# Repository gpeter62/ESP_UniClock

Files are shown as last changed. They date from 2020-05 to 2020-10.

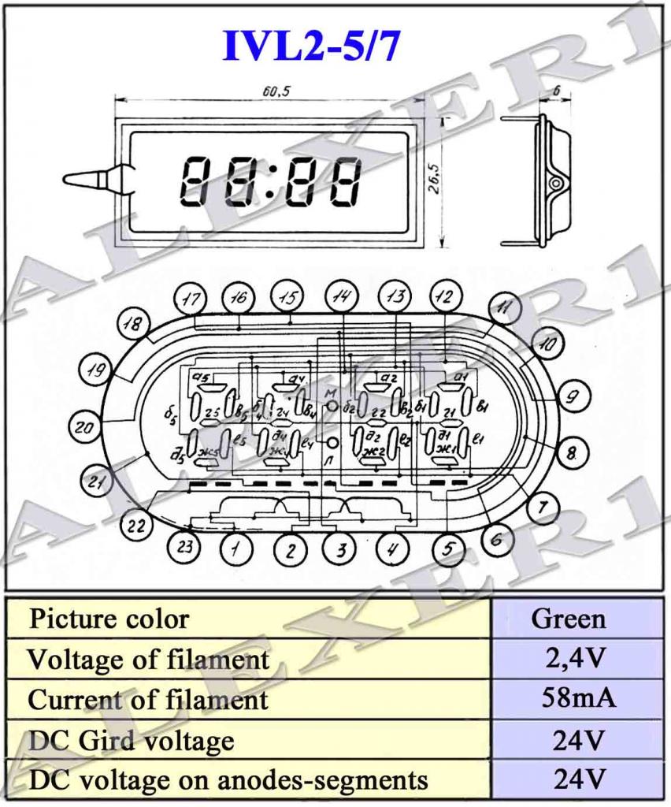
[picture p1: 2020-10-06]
Datasheets/IVL2-7_5-VFD-Specs.jpg

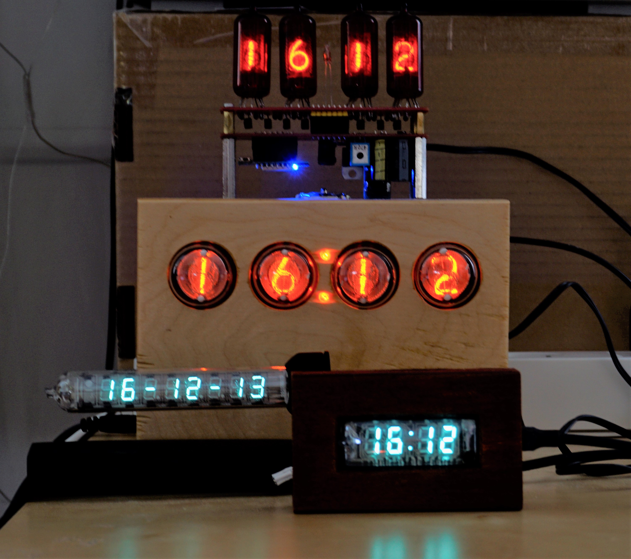
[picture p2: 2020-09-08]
_DSC3223.jpg

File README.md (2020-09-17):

# ESP_UniClock v1.4

Universal WifiClock with Nixie, VFD, Numitron tubes or LED display
Number of digits: 4, 6 or 8

Adjustable day and night brightness

ANIMATE: 5 animation modes, 6 means random animation

Hardver:

Wemos D1 Mini (or any other ESP8266 modul) 160MHz

Drivers: SN74141 (multiplex or latch), MAX6921, MAX7219, MM5450

Optional: DS18B20 temperature sensor  (1 or 2 sensor)
 
Optional: DHT11/DHT22 temperature/humidity sensor

Optional: DS3231 RTC Clock with Wifi/Manual mode switch and pushbuttons to set the date/time - standalone mode possible without WiFi

Optional: GPS modul (to use instead of Wifi sync  - standalone mode, only web setup screen available)

User defined pin numbers for digits and segments

Web page for setup. See: Screenshot.png

-- External libraries used ------------------------------------------------------------------------------

Time, Timezone, NtpClient, Wifimanager       Optional: DS3231, TinyGPSPlus, 
--------------------------------------------------------------------------------------------------------

More info:

Peter Gautier
 Email: gautier.p62@gmail.com

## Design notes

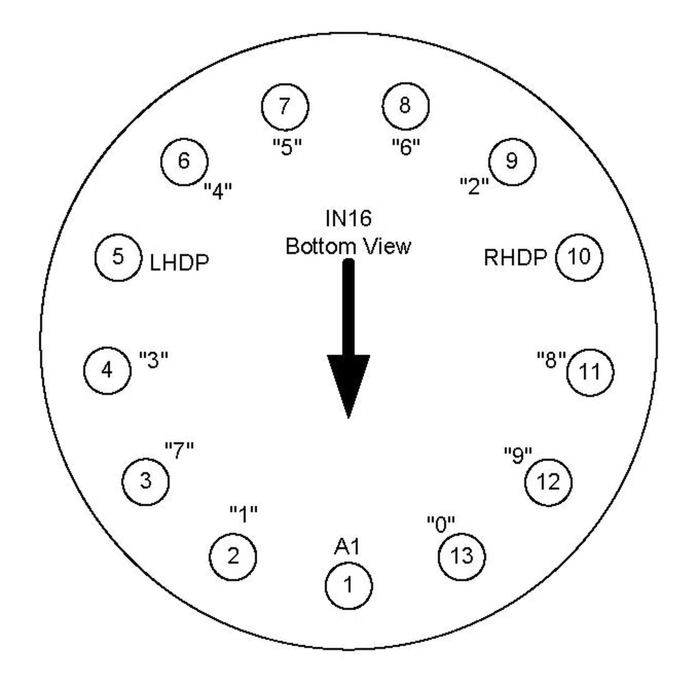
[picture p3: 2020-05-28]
Datasheets/in16_pinout__26559.1553434410.webp

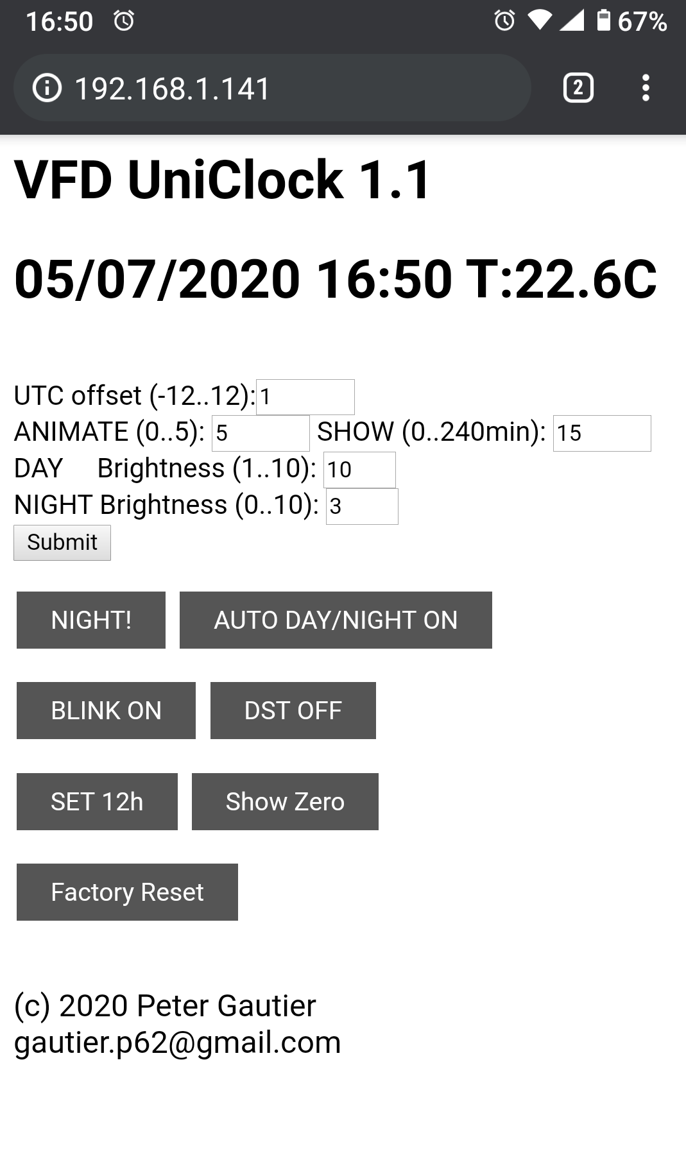
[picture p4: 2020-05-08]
Screenshot.png

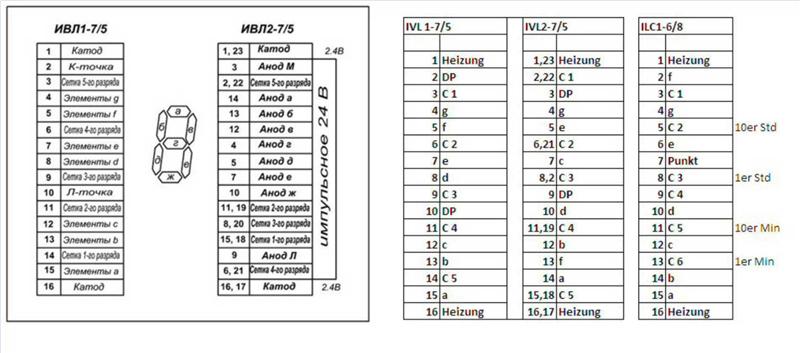
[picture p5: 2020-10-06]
Datasheets/IVL2-57 Pins.jpg

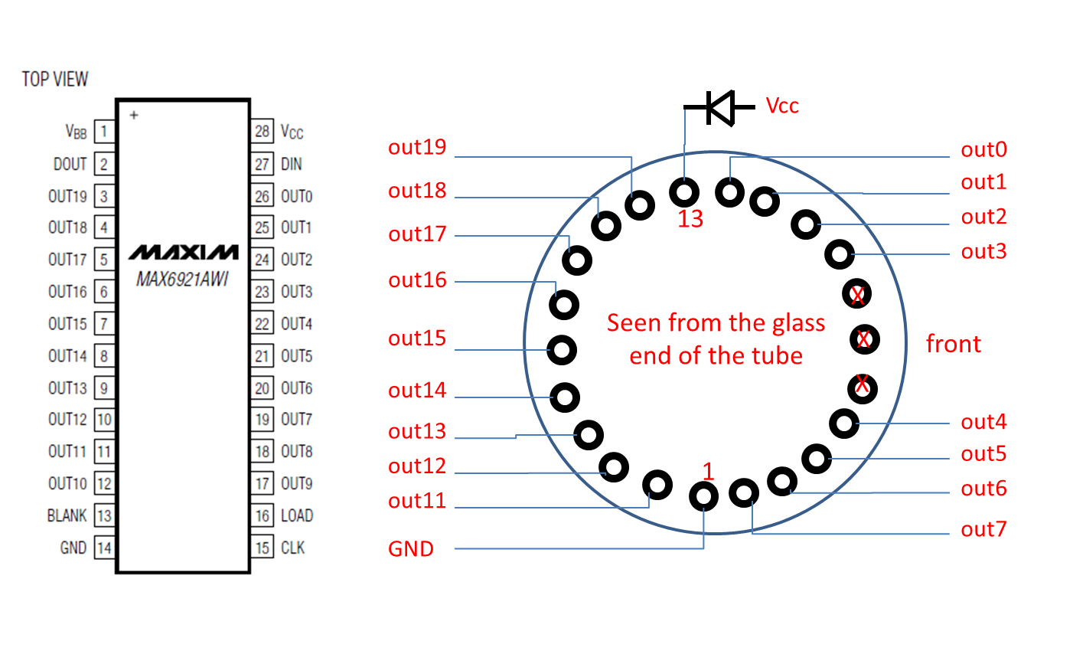
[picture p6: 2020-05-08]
Datasheets/max6921_-_IV18.png

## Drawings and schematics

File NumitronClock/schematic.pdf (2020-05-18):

6 FTDI | R⁵ | R⁶ R⁷

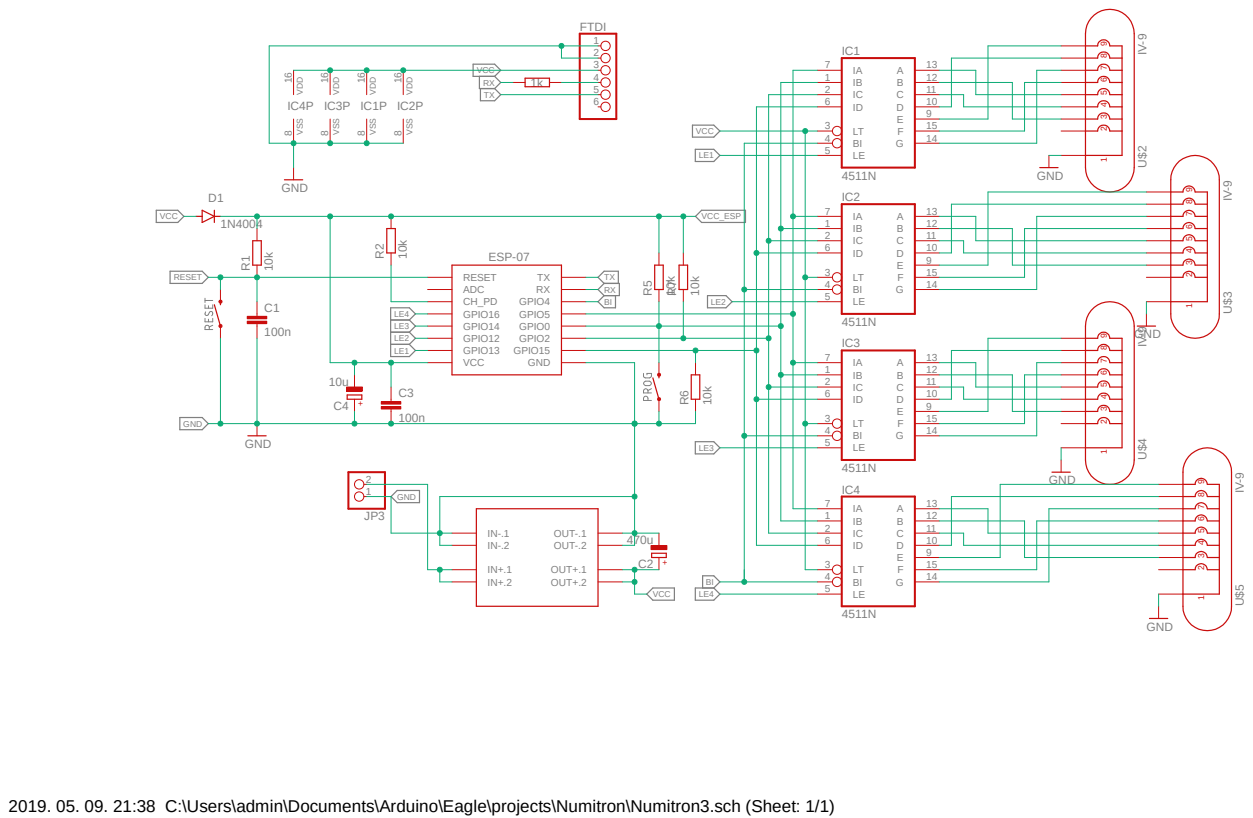
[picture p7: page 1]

ID 6 | 10 C
LT 3 BI 4 LE 5 | 9

IB 1 | 12 A
IC 2 | 11 B

IB 1 | 12 A 11 B
IC 2

2019. 05. 09. 21:38 C:\Users\admin\Documents\Arduino\Eagle\projects\Numitron\Numitron3.sch (Sheet: 1/1)

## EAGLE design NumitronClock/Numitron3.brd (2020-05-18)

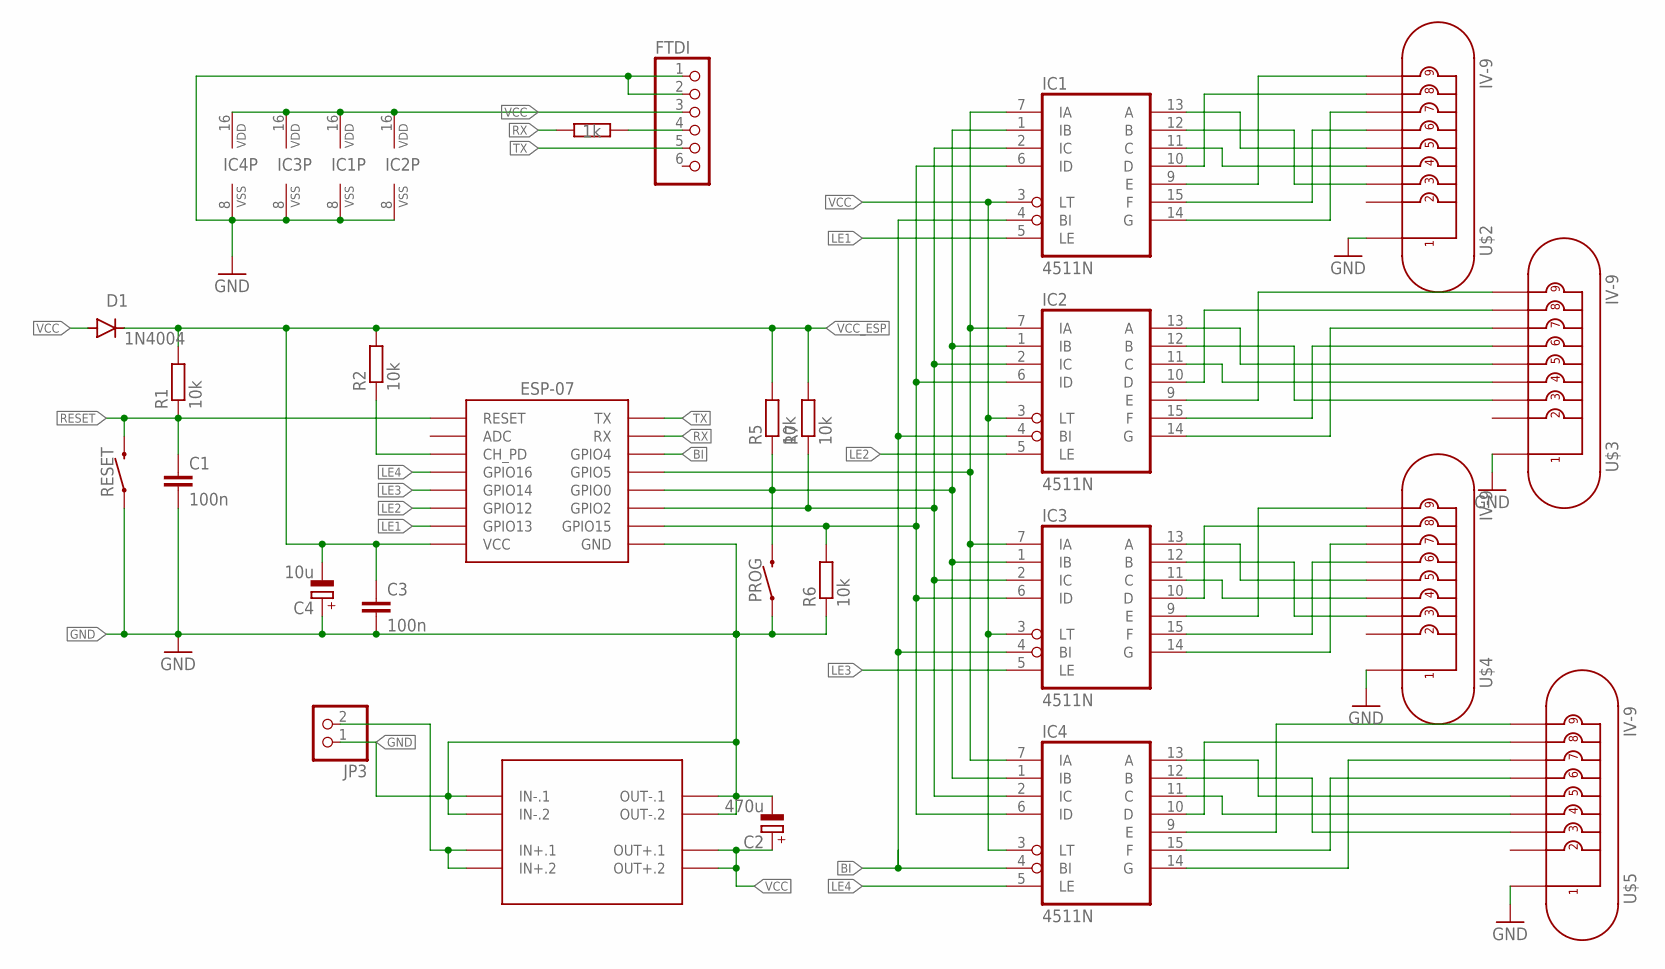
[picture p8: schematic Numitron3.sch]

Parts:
C1: 100n; C025-024X044
C2: 470u; B45181B
C3: 100n; C025-050X050
C4: 10u; B45181A
D1: 1N4004; DO41-10
ESP-07: ESP12SMD; ESP12-SMD
FTDI: PINHD-1X6; 1X06
IC1, IC2, IC3, IC4: 4511N; DIL16
JP3: PINHD-1X2; 1X02
PROG: MOMENTARY-SWITCH-SPST-PTH-6.0MM; TACTILE_SWITCH_PTH_6.0MM
R1, R2, R5, R6, R7: 10k; 0204/7
R4: 1k; 0204/7
RESET: MOMENTARY-SWITCH-SPST-PTH-6.0MM; TACTILE_SWITCH_PTH_6.0MM
U$2, U$3, U$4, U$5: IV-9
U$6: DC-DC-STEP-DOWN-MP1584

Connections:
BI: ESP-07.GPIO4, IC1.4 (BI), IC2.4 (BI), IC3.4 (BI), IC4.4 (BI)
GND: C1.2, C2.-, C3.2, C4.+, ESP-07.GND, FTDI.1, FTDI.2, IC1.8 (VSS), IC2.8 (VSS), IC3.8 (VSS), IC4.8 (VSS), JP3.1, PROG.1, R6.1, RESET.1, U$2.1, U$3.1, U$4.1, U$5.1, U$6.IN-.1, U$6.IN-.2, U$6.OUT-.1, U$6.OUT-.2
LE1: ESP-07.GPIO13, IC1.5 (LE)
LE2: ESP-07.GPIO12, IC2.5 (LE)
LE3: ESP-07.GPIO14, IC3.5 (LE)
LE4: ESP-07.GPIO16, IC4.5 (LE)
unnamed: ESP-07.GPIO5, IC1.7 (IA), IC2.7 (IA), IC3.7 (IA), IC4.7 (IA)
unnamed: ESP-07.GPIO0, IC1.1 (IB), IC2.1 (IB), IC3.1 (IB), IC4.1 (IB), PROG.3 (2), R5.1
unnamed: ESP-07.GPIO2, IC1.2 (IC), IC2.2 (IC), IC3.2 (IC), IC4.2 (IC), R7.1
unnamed: ESP-07.GPIO15, IC1.6 (ID), IC2.6 (ID), IC3.6 (ID), IC4.6 (ID), R6.2
unnamed: IC1.13 (A), U$2.5
unnamed: IC1.12 (B), U$2.3
unnamed: IC1.11 (C), U$2.4
unnamed: IC1.10 (D), U$2.8
unnamed: IC1.9 (E), U$2.9
unnamed: IC1.15 (F), U$2.6
unnamed: IC1.14 (G), U$2.7
unnamed: IC2.14 (G), U$3.7
unnamed: IC2.12 (B), U$3.3
unnamed: IC2.13 (A), U$3.5
unnamed: IC2.10 (D), U$3.8
unnamed: IC2.9 (E), U$3.9
unnamed: IC2.11 (C), U$3.4
unnamed: IC2.15 (F), U$3.6
unnamed: IC3.9 (E), U$4.9
unnamed: IC3.13 (A), U$4.5
unnamed: IC3.12 (B), U$4.3
unnamed: IC3.15 (F), U$4.6
unnamed: IC3.14 (G), U$4.7
unnamed: IC3.10 (D), U$4.8
unnamed: IC3.11 (C), U$4.4
unnamed: IC4.14 (G), U$5.7
unnamed: IC4.15 (F), U$5.6
unnamed: IC4.9 (E), U$5.9
unnamed: IC4.10 (D), U$5.8
unnamed: IC4.11 (C), U$5.4
unnamed: IC4.12 (B), U$5.3
unnamed: IC4.13 (A), U$5.5
unnamed: ESP-07.CH_PD, R2.1
unnamed: JP3.2, U$6.IN+.1, U$6.IN+.2
unnamed: FTDI.4, R4.1
RESET: C1.1, ESP-07.RESET, R1.1, RESET.3 (2)
RX: ESP-07.RXD0 (RX), R4.2
TX: ESP-07.TXD0 (TX), FTDI.5
VCC: C2.+, D1.A, FTDI.3, IC1.3 (LT), IC1.16 (VDD), IC2.3 (LT), IC2.16 (VDD), IC3.3 (LT), IC3.16 (VDD), IC4.3 (LT), IC4.16 (VDD), U$6.OUT+.1, U$6.OUT+.2
VCC_ESP: C3.1, C4.-, D1.C, ESP-07.VCC, R1.2, R2.2, R5.2, R7.2

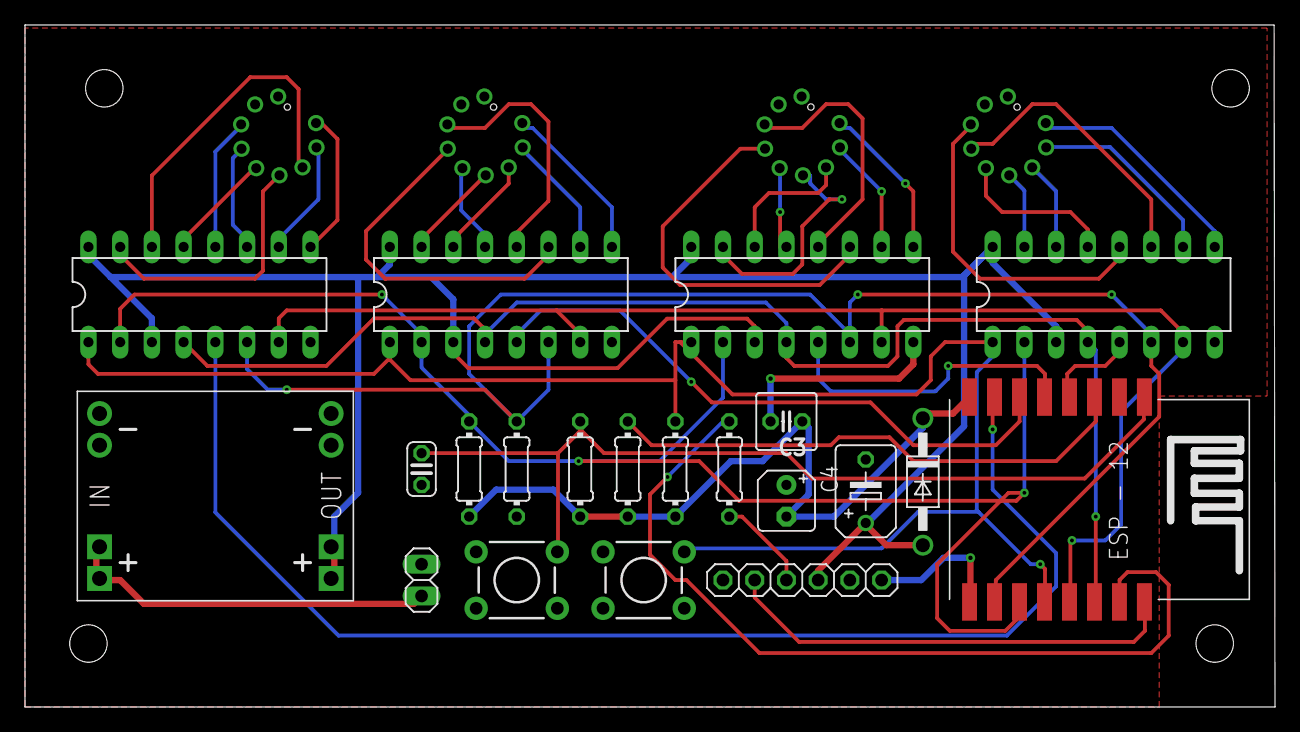
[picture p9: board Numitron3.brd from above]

Board: 2 copper layers, 100.1 x 54.6 mm, 25 parts (0 on the bottom side), 46 nets.

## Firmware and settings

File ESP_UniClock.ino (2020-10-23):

/* 
 *    Universal Clock  Nixie, VFD, LED, Numitron
 *    with optional Dallas Thermometer and DS3231 RTC
 *    v1.4g  22/09/2020
 *    Copyright (C) 2020  Peter Gautier 
 *    
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
 *    Always check the usable pins of 8266:
 *    https://randomnerdtutorials.com/esp8266-pinout-reference-gpios/
 */
//---------------------------- PROGRAM PARAMETERS -------------------------------------------------
#define DEBUG
//#define USE_DALLAS_TEMP   //TEMP_SENSOR_PIN is used to connect the sensor
//#define USE_DHT_TEMP        //TEMP_SENSOR_PIN is used to connect the sensor
//#define USE_RTC           //I2C pins are used!   SCL = D1 (GPIO5), SDA = D2 (GPIO4)
//#define USE_GPS           
#define USE_NEOPIXEL_MAKUNA      //WS2812B led stripe, below tubes
//#define USE_NEOPIXEL_ADAFRUIT    //WS2812B led stripe, below tubes

#define MAXBRIGHTNESS 10  // (if MM5450, use 15 instead of 10)

//Use only 1 from the following options!
#define MULTIPLEX74141    //4..8 Nixie tubes
//#define NO_MULTIPLEX74141 //4..6 Nixie tubes
//#define MAX6921           //4..8 VFD tubes   (IV18)
//#define MM5450            //6..8 LEDS
//#define MAX7219CNG        //4..8 LED 
//#define Numitron_4511N
//#define SN75512           //4..8 VFD tubes   
//#define samsung           //samsung serial display
//#define PCF_MULTIPLEX74141

#define COLON_PIN   16       //Blinking Colon pin.  If not used, SET TO -1  (redtube clock:2, IV16:16)
#define TEMP_SENSOR_PIN -1  //DHT or Dallas temp sensor pin.  If not used, SET TO -1   (RX or any other free pin)
#define LED_SWITCH_PIN -1   //external led lightning.  If not used, SET TO -1
#define DECIMALPOINT_PIN -1 //Nixie decimal point between digits (thermometer, hygrometer). If not used, SET TO -1

//Display temperature and date in every minute between START..END seconds
#define ENABLE_CLOCK_DISPLAY true   //false, if no clock display is needed (for example: thermometer + hygrometer only)
#define TEMP_START  35
#define TEMP_END    40
#define HUMID_START  50
#define HUMID_END    55
#define DATE_START  45
#define DATE_END    50
#define ANIMSPEED   50  //Animation speed in millisec 
#define TEMP_CHARCODE 15    
#define GRAD_CHARCODE 16
#define PERCENT_CHARCODE 8

uint8_t c_MinBrightness = 8; 
uint8_t c_MaxBrightness = 255;
//--------------------------------------------------------------------------------------------------

#if defined(ESP8266)  
  char webName[] = "UniClock 1.4g";
  #define AP_NAME "UNICLOCK"
  #define AP_PASSWORD ""
  #include <ESP8266WiFi.h>
  #include <ESP8266mDNS.h>
#elif defined(ESP32)
  char webName[] = "ESP32UniClock 1.4g";
  #define AP_NAME "UNICLOCK32"
  #define AP_PASSWORD ""
  #include <WiFi.h>
  #include <ESPmDNS.h>
#else
  #error "Board is not supported!"  
#endif

#include <NTPClient.h>
#include <WiFiUdp.h>
#include <TimeLib.h>
#include <Timezone.h>
#include <Wire.h>
#include <WiFiManager.h>
#include <EEPROM.h>

#ifdef USE_NEOPIXEL_MAKUNA
#include <NeoPixelBrightnessBus.h>  //<NeoPixelBus.h>
#endif

#ifdef USE_NEOPIXEL_ADAFRUIT
#endif

extern void ICACHE_RAM_ATTR writeDisplay();
extern void writeDisplaySingle();
extern void setup_pins();
extern int maxDigits;

const char* ssid = AP_NAME;  // Enter SSID here
const char* password = AP_PASSWORD;  //Enter Password here
WiFiServer server(80);
String header;

#define BUFSIZE 10
byte digit[BUFSIZE];
byte newDigit[BUFSIZE];
byte oldDigit[BUFSIZE];
boolean digitDP[BUFSIZE];   //actual value to put to display
boolean digitsOnly = true;  //only 0..9 numbers are possible to display?
byte animMask[BUFSIZE];     //0 = no animation mask is used

boolean EEPROMsaving = false; //saving in progress - stop display refresh
 
// 8266 internal pin registers
// https://github.com/esp8266/esp8266-wiki/wiki/gpio-registers
// example: https://github.com/mgo-tec/OLED_1351/blob/master/src/OLED_SSD1351.cpp


#ifdef DEBUG    //Macros are usually in all capital letters.
  #define DPRINT(...)       Serial.print(__VA_ARGS__)     //DPRINT is a macro, debug print
  #define DPRINTLN(...)     Serial.println(__VA_ARGS__)   //DPRINT is a macro, debug print
  #define DPRINTBEGIN(...)  Serial.begin(__VA_ARGS__)     //DPRINTLN is a macro, debug print with new line
#else
  #define DPRINT(...)     //now defines a blank line
  #define DPRINTLN(...)   //now defines a blank line
  #define DPRINTBEGIN(...)   //now defines a blank line
#endif

#define PIN_OUT_SET PERIPHS_GPIO_BASEADDR + 4
#define PIN_OUT_CLEAR PERIPHS_GPIO_BASEADDR + 8

bool colonBlinkState = false;

WiFiUDP ntpUDP;
NTPClient timeClient(ntpUDP, "pool.ntp.org", 0, 7200000); // Update time every two hours
IPAddress ip; 

// Set timezone rules.  Offsets set to zero, since they will be loaded from EEPROM
TimeChangeRule myDST = {"DST", Last, Sun, Mar, 2, 0};    
TimeChangeRule mySTD = {"STD", First, Sun, Nov, 2, 0};     
Timezone myTZ(myDST, mySTD);

boolean clockWifiMode = true;

byte useTemp = 0;   //number of temp sensors: 0,1,2
float temperature[2] = {0,0};
byte useHumid = 0;
float humid = 0;

//----------------- EEPROM addresses -------------------------------------------------------------------
const int EEPROM_addr = 0;

struct {
  int utc_offset =1;
  bool enableDST = true;           // Flag to enable DST (summer time...)
  bool set12_24 = true;            // Flag indicating 12 vs 24 hour time (false = 12, true = 24);
  bool showZero = true;            // Flag to indicate whether to show zero in the hour ten's place
  bool enableBlink = true;         // Flag to indicate whether center colon should blink
  int  interval = 15;              // prm.interval in minutes, with 0 = off
  bool enableAutoShutoff = true;   // Flag to enable/disable nighttime shut off
  byte dayHour = 8;                // start of daytime
  byte dayMin = 0;
  byte nightHour = 22;             // start of night time
  byte nightMin = 0;
  byte dayBright = MAXBRIGHTNESS;  // display daytime brightness
  byte nightBright = 5;            // display night brightness
  byte animMode = 2;               //0=no anim,  if 1 or 2 is used, animation, when a digit changes
  byte rgbEffect = 1;              //0=OFF, 1=FixColor
  byte rgbBrightness = 100;
  int rgbFixColor = 150;           //0..255, 256 = white
  byte rgbSpeed = 50;              //0..255msec / step
  byte magic = 133;                //magic value, to check EEPROM at first start
} prm;


//-------------------------------------------------------------------------------------------------------
time_t prevTime = 0;
time_t protectTimer = 0;
bool displayON = true;
bool manualOverride = false;
bool initProtectionTimer = false;  // Set true at the top of the hour to synchronize protection timer with clock
bool decimalpointON = false;

void configModeCallback (WiFiManager *myWiFiManager) {
  DPRINTLN("Switch to AP config mode...");
  DPRINTLN("To configure Wifi,  ");
  DPRINT("connect to Wifi network "); DPRINTLN(ssid);
  DPRINTLN("and open 192.168.4.1 in web browser");
  }

void clearDigits() {
  memset(oldDigit,10,sizeof(oldDigit));
  memset(digit,10,sizeof(digit));
  memset(newDigit,10,sizeof(newDigit));
  memset(digitDP,0,sizeof(digitDP));
}


void startWifiMode() {
    int count = 0;
    
    EEPROMsaving = true;
    DPRINTLN("Starting Clock in WiFi Mode!");
    WiFiManager MyWifiManager;
    MyWifiManager.setCleanConnect(true);
    MyWifiManager.setAPCallback(configModeCallback);
    MyWifiManager.setEnableConfigPortal(false);
    for (int i=0;i<5;i++) {
      if(!MyWifiManager.autoConnect(AP_NAME,AP_PASSWORD)) {
        DPRINT("Retry to Connect:"); DPRINTLN(i);
        WiFi.disconnect();
        WiFi.mode(WIFI_OFF);
        delay(2000);
        if (i==4) {
          MyWifiManager.setEnableConfigPortal(true);
          MyWifiManager.autoConnect(AP_NAME,AP_PASSWORD); // Default password is PASSWORD, change as needed
        }
      }
      else 
        break;
    }  //end for
    ip = WiFi.localIP();
    WiFi.setAutoReconnect(true);
    WiFi.mode(WIFI_STA);
    EEPROMsaving = false;

    DPRINTLN("Connecting to Time Server...");
    timeClient.begin();
    timeClient.forceUpdate();
    while (true) { 
      delay(100);
      if (timeClient.update()) break;
      count ++; if (count>999) count = 1;
      writeIpTag(count);
      delay(500); 
    }
    server.begin();
    clearDigits();
    showMyIp();  
    calcTime();    
}


void startStandaloneMode() {
    DPRINTLN("Starting Clock in Standalone Mode!");
    DPRINT("Clock's wifi SSID:"); DPRINTLN(ssid);
    DPRINTLN("IP: 192.168.4.1");
    EEPROMsaving = true;
    WiFi.mode(WIFI_AP);
    delay(100);
    IPAddress local_ip(192,168,4,1);
    IPAddress gateway(192,168,4,1);
    IPAddress subnet(255,255,255,0);
    WiFi.softAPConfig(local_ip, gateway, subnet);
    DPRINT("AP status:"); DPRINTLN(WiFi.softAP(ssid, password,12) ? "Ready" : "Failed!");  //channel
    DPRINT("Mac address:"); DPRINTLN(WiFi.softAPmacAddress());
    ip = WiFi.softAPIP();
    EEPROMsaving = false;
    delay(1000);
    server.begin();
    clearDigits();
    showMyIp();  
    calcTime();
}


void setup() {
  //WiFi.mode(WIFI_OFF);
  delay(200);
  DPRINTBEGIN(115200); DPRINTLN(" ");
  clearDigits(); 
  delay(100);
  if (COLON_PIN>=0)  pinMode(COLON_PIN, OUTPUT);
  if (LED_SWITCH_PIN>=0)  pinMode(LED_SWITCH_PIN, OUTPUT);
  if (DECIMALPOINT_PIN>=0)  pinMode(DECIMALPOINT_PIN, OUTPUT);
  decimalpointON = false;
  if (TEMP_SENSOR_PIN>0) {
    setupTemp();
    setupDHTemp();
  }  
  setupRTC();
  setupGPS();

  DPRINT("Number of digits:"); DPRINTLN(maxDigits);
  loadEEPROM();
  if (prm.magic !=133) factoryReset();
  
  setupNeopixelMakuna();  
  setupNeopixelAdafruit();  
  setup_pins();
  testTubes(300);
  clearDigits();
  delay(100);
  checkWifiMode();
  if (clockWifiMode) 
    startWifiMode();
  else 
    startStandaloneMode();
}

void calcTime() {
  mySTD.offset = prm.utc_offset * 60;
  myDST.offset = mySTD.offset;
  if (prm.enableDST) { myDST.offset += 60; }
  myTZ = Timezone(myDST, mySTD);

  if (clockWifiMode) {
    if (WiFi.status() == WL_CONNECTED) {
      if (timeClient.update()) {
        setTime(myTZ.toLocal(timeClient.getEpochTime()));
        if (year()>2019) 
          updateRTC();    //update RTC, if needed
        else {
          getRTC();  
          getGPS();
        }
      } //endif update?
    }  //endif Connected?
    else {
        getRTC();  
        getGPS();
    }
  }  //endif (clockWifiMode)
  else {  //standalone mode!
    getRTC();
    getGPS();
  }
}


void timeProgram() {
static unsigned long lastRun = millis();
  doAnimationMakuna();
  doAnimationAdafruit();
  if ((millis()-lastRun)<300) return;

  lastRun = millis(); 
  calcTime();
  if (useTemp>0) {
    requestTemp(false);
    getTemp(); 
  }
  getDHTemp();
  if (prm.interval > 0) {  // protection is enabled
      // At the first top of the hour, initialize protection logic timer
      if (!initProtectionTimer && (minute() == 0)) {  
        protectTimer = 0;   // Ensures protection logic will be immediately triggered                                     
        initProtectionTimer = true;
      }
      if ((now() - protectTimer) >= 60 * prm.interval) {
        protectTimer = now();
        // The current time can drift slightly relative to the protectTimer when NIST time is updated
        // Need to make a small adjustment to the timer to ensure it is triggered at the minute change
        protectTimer -= ((second()+30)%60 - 30);  
        if (displayON) cathodeProtect();
      }      
  }
  
  if (now() != prevTime) { // Update time every second
    prevTime = now();
    evalShutoffTime();     // Check whether display should be turned off (Auto shutoff mode)
    if (!displayON || !prm.enableBlink) colonBlinkState = false;  
    else colonBlinkState = (bool)(second() % 2);
    
    if (maxDigits>=8)        displayTime8();         
    else if (maxDigits==6)   displayTime6(); 
    else displayTime4();
    
 //   if (COLON_PIN>=0) digitalWrite(COLON_PIN,colonBlinkState);  // Blink colon pin
    if ((LED_SWITCH_PIN>=0) && displayON) //Switch on underlightning LED only daytime
      digitalWrite(LED_SWITCH_PIN,HIGH);   
    else 
      digitalWrite(LED_SWITCH_PIN,LOW);
    printDigits(0);
    writeDisplaySingle();
  }
}


void loop() {  
  
  timeProgram();
  checkWifiMode();
  if (clockWifiMode) { //Wifi Clock Mode
    if (WiFi.status() == WL_CONNECTED) wifiCode();
    else {
      WiFi.reconnect();
      wifiCode();
      resetWiFi();
    }  
  }
  else {   //Manual Clock Mode
     wifiCode();
     editor();
  } //endelse
  yield();
}

void loadEEPROM() {
  DPRINTLN("Loading setting from EEPROM.");
  EEPROMsaving = true;  
  EEPROM.begin(sizeof(prm));
  EEPROM.get(EEPROM_addr,prm);
  EEPROM.end();
  EEPROMsaving = false;
}

void saveEEPROM() {
  EEPROMsaving = true;
  EEPROM.begin(sizeof(prm));
  EEPROM.put(EEPROM_addr,prm);     //(mod(mySTD.offset/60,24))); 
  EEPROM.commit();
  EEPROM.end();
  EEPROMsaving = false;
}

void factoryReset() {
  prm.utc_offset = 1;
  prm.enableDST = true;          // Flag to enable DST (summer time...)
  prm.set12_24 = true;           // Flag indicating 12 vs 24 hour time (false = 12, true = 24);
  prm.showZero = true;           // Flag to indicate whether to show zero in the hour ten's place
  prm.enableBlink = true;        // Flag to indicate whether center colon should blink
  prm.interval = 15;             // prm.interval in minutes, with 0 = off
  prm.enableAutoShutoff = true;  // Flag to enable/disable nighttime shut off
  prm.dayHour = 7;
  prm.dayMin = 0;
  prm.nightHour = 22;
  prm.nightMin = 0;
  prm.dayBright = MAXBRIGHTNESS;
  prm.nightBright = 3;
  prm.animMode = 6;  
  prm.rgbEffect = 1;
  prm.rgbBrightness = 100;
  prm.rgbFixColor = 150;
  prm.rgbSpeed = 50;      
  prm.magic = 133;              //magic value to check to first start
  saveEEPROM();
  calcTime();
  DPRINTLN("Factory Reset!!!");
}

void cathodeProtect() {
  int hour12_24 = prm.set12_24 ? (byte)hour() : (byte)hourFormat12();
  byte hourShow = (byte)hour12_24;
  byte minShow  = (byte)minute();
  byte secShow  = (byte)second();
  byte dh1 = (hourShow /10), dh2 = (hourShow %10); 
  byte dm1 = (minShow /10),  dm2 = (minShow %10);
  byte ds1 = (secShow /10),  ds2 = (secShow %10);

  // All four digits will increment up at 10 Hz.
  // At T=2 sec, individual digits will stop at 
  // the correct time every second starting from 
  // the right and ending on the left
  for (int i = 0; i <= 70; i++){
    if (i >= 20) ds2 = (secShow % 10); 
    if (i >= 30) ds1 = (secShow /10); 
    if (i >= 40) dm2 = (minShow % 10);
    if (i >= 50) dm1 = (minShow / 10);
    if (i >= 60) dh2 = (hourShow % 10);
    if (i == 70) dh1 = (hourShow / 10);
    if (maxDigits>=8) {
      digit[7] = dh1;
      digit[6] = dh2;
      digit[5] = 11;
      digit[4] = dm1;
      digit[3] = dm2;
      digit[2] = 11;
      digit[1] = ds1;
      digit[0] = ds2;
    }
    else if (maxDigits==6) {
      digit[5] = dh1;
      digit[4] = dh2;
      digit[3] = dm1;
      digit[2] = dm2;
      digit[1] = ds1;
      digit[0] = ds2;
    }
    else {
      digit[3] = dh1;
      digit[2] = dh2;
      digit[1] = dm1;
      digit[0] = dm2;
    }
    incMod10(dh1); incMod10(dh2);
    incMod10(dm1); incMod10(dm2);
    incMod10(ds1); incMod10(ds2);
    delay(100);
  }
  memcpy(oldDigit,digit,sizeof(oldDigit));
}

inline void incMod10(byte &x) { x = (x + 1 == 10 ? 0: x + 1); };


void displayTemp(byte ptr){
int digPtr = 0;
  for (int i=0;i<maxDigits;i++) {
    digitDP[i] = false; 
    newDigit[i] = 10; 
  }

  newDigit[digPtr++] = TEMP_CHARCODE;  //  "C"
  if (maxDigits>4) newDigit[digPtr++] = GRAD_CHARCODE;   //grad
  
  newDigit[digPtr++] = int(temperature[ptr]*10) % 10; 
  digitDP[digPtr] = true;
  newDigit[digPtr++] = int(temperature[ptr]) % 10;
  
  newDigit[digPtr] = int(temperature[ptr]) / 10; 
  if (newDigit[digPtr]==0) newDigit[digPtr] = 10;  //BLANK!!!
  if (prm.animMode == 0)  memcpy(oldDigit,newDigit,sizeof(oldDigit));  //don't do animation
  colonBlinkState = true;
  decimalpointON = true;
}  

void displayHumid(){
int digPtr = 0;
  for (int i=0;i<maxDigits;i++) {
    digitDP[i] = false; 
    newDigit[i] = 10; 
  }

  newDigit[digPtr++] = PERCENT_CHARCODE;  //  "%"
  newDigit[digPtr++] = int(humid*10) % 10; 
  digitDP[digPtr] = true;
  newDigit[digPtr++] = int(humid) % 10;
  
  newDigit[digPtr] = int(humid) / 10; 
  if (newDigit[digPtr]==0) newDigit[digPtr] = 10;  //BLANK!!!
  if (prm.animMode == 0)  memcpy(oldDigit,newDigit,sizeof(oldDigit));  //don't do animation
  colonBlinkState = true;
  decimalpointON = true;
} 

void displayTime4(){
  for (int i=0;i<maxDigits;i++) digitDP[i] = false;
  digitDP[4] = true;   digitDP[2] = true;    
  int hour12_24 = prm.set12_24 ? (byte)hour() : (byte)hourFormat12();
  if ((useTemp==2) && (second()>=TEMP_START+(TEMP_END-TEMP_START)/2) && (second()<TEMP_END)) displayTemp(1);
  else if ((useTemp>0) && (second()>=TEMP_START) && (second()<TEMP_END)) displayTemp(0);
  else if ((useHumid>0) && (second()>=HUMID_START) && (second()<HUMID_END)) displayHumid();
  else if ((ENABLE_CLOCK_DISPLAY) && (second()>=DATE_START)&& (second()<DATE_END)) {    
        newDigit[3] = month() / 10;
        newDigit[2] = month() % 10;   
        digitDP[2] = true; 
        newDigit[1] = day() / 10;
        newDigit[0] = day() % 10;
        colonBlinkState = true;
        }
      else if (ENABLE_CLOCK_DISPLAY){
        newDigit[3] = hour12_24 / 10;
        if ((!prm.showZero)  && (newDigit[3] == 0)) newDigit[3] = 10;
        newDigit[2] = hour12_24 % 10;
        newDigit[1] = minute() / 10;
        newDigit[0] = minute() % 10;
        if (prm.enableBlink && (second()%2 == 0)) digitDP[2] = false;  
       }
   changeDigit();    
}

void displayTime6(){
  for (int i=0;i<maxDigits;i++) digitDP[i] = false;
  digitDP[4] = true;   digitDP[2] = true;    
  int hour12_24 = prm.set12_24 ? (byte)hour() : (byte)hourFormat12();
  if ((useTemp==2) && (second()>=TEMP_START+(TEMP_END-TEMP_START)/2) && (second()<TEMP_END)) displayTemp(1);
  else if ((useTemp>0) && (second()>=TEMP_START) && (second()<TEMP_END)) displayTemp(0);
  else if ((useHumid>0) && (second()>=HUMID_START) && (second()<HUMID_END)) displayHumid();
  else if (ENABLE_CLOCK_DISPLAY && (second()>=DATE_START)&& (second()<DATE_END)) {    
        newDigit[5] = (year()%100) / 10;
        newDigit[4] = year() % 10;
        digitDP[4] = true;
        newDigit[3] = month() / 10;
        newDigit[2] = month() % 10;   
        digitDP[2] = true; 
        newDigit[1] = day() / 10;
        newDigit[0] = day() % 10;
        colonBlinkState = true;
        }
      else if (ENABLE_CLOCK_DISPLAY){
        newDigit[5] = hour12_24 / 10;
        if ((!prm.showZero)  && (newDigit[5] == 0)) newDigit[5] = 10;
        newDigit[4] = hour12_24 % 10;
        newDigit[3] = minute() / 10;
        newDigit[2] = minute() % 10;
        if (prm.enableBlink && (second()%2 == 0)) digitDP[2] = false;  
        newDigit[1] = second() / 10;
        newDigit[0] = second() % 10;
      }
  changeDigit();    
}

void displayTime8(){
  for (int i=0;i<maxDigits;i++) {digitDP[i] = false; newDigit[i] = 10;}
  int hour12_24 = prm.set12_24 ? (byte)hour() : (byte)hourFormat12();
  if ((useTemp==2) && (second()>=TEMP_START+(TEMP_END-TEMP_START)/2) && (second()<TEMP_END)) displayTemp(1);
  else if ((useTemp>0) && (second()>=TEMP_START) && (second()<TEMP_END)) displayTemp(0);
  else if ((useHumid>0) && (second()>=HUMID_START) && (second()<HUMID_END)) displayHumid();
  else {
    if (ENABLE_CLOCK_DISPLAY && (second()>=DATE_START) && (second()<DATE_END)) {    
      newDigit[7] = year() / 1000;
      newDigit[6] = (year()%1000) / 100;    
      newDigit[5] = (year()%100) / 10;
      newDigit[4] = year() % 10;
      digitDP[4] = true;
      newDigit[3] = month() / 10;
      newDigit[2] = month() % 10;   
      digitDP[2] = true; 
      newDigit[1] = day() / 10;
      newDigit[0] = day() % 10;
      colonBlinkState = true;
      if (prm.animMode == 1)  memcpy(oldDigit,newDigit,sizeof(oldDigit));  //don't do animation
    }
    else if (ENABLE_CLOCK_DISPLAY){
      newDigit[8] = 10;  //sign digit = BLANK
      newDigit[7] = hour12_24 / 10;
      if ((!prm.showZero)  && (newDigit[7] == 0)) newDigit[7] = 10;
      newDigit[6] = hour12_24 % 10;
      newDigit[5] = 11;  //- sign
      newDigit[4] = minute() / 10;
      newDigit[3] = minute() % 10;
      newDigit[2] = 11;  //- sign
      if (prm.enableBlink && (second()%2 == 0)) newDigit[2] = 10;  //BLANK
      newDigit[1] = second() / 10;
      newDigit[0] = second() % 10;
    }
  }
  changeDigit();
}
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

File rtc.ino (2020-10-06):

#ifdef USE_RTC

//------ Mode Switch and Push Buttons ---------------------
#define PIN_MODE_SWITCH  17   //Analog A0 port!!!    
#define PIN_FLD_BUTTON   16     
#define PIN_SET_BUTTON   0    

//------- I2C bus definition   Any pins are usable --------
//#define PIN_SDA 4           //D2   original general setup
//#define PIN_SCL 5           //D1

#define PIN_SDA 5           //D1   SDA/SCL changed
#define PIN_SCL 4           //D2

#define MENU_UNSELECT_TIMEOUT 30000

#include <ds3231.h>    //https://github.com/rodan/ds3231
struct ts tim;

int monthdays[13] = {0,31,29,31,30,31,30,31,31,30,31,30,31};

struct Menu {
   short lowlimit;        // alsó határ
   short uplimit;         // felső határ
   char _name[10];
};

const struct Menu m1[]= {
  {0,0,"not used"},
  {2018,2099,"year"},
  {1,12,"month"},
  {1,31,"day"},
  {0,23,"hour"},
  {0,59,"minute"},
};

#define MAXFLD 5 

int mvar[MAXFLD+1];

enum switchStates {IS_OPEN, IS_OPENING, IS_PUSHED, IS_LONGPRESSING, IS_LONGPRESSED, IS_PUSHING, IS_LONGOPENING};

int fld = 0;
unsigned long LastModify = 0;

void setupRTC() {
  pinMode(PIN_MODE_SWITCH,INPUT_PULLUP);   DPRINT("- MODE Switch : GPIO"); DPRINTLN(PIN_MODE_SWITCH);
  pinMode(PIN_FLD_BUTTON,INPUT_PULLUP);    DPRINT("- FIELD Button: GPIO"); DPRINTLN(PIN_FLD_BUTTON); 
  pinMode(PIN_SET_BUTTON,INPUT_PULLUP);    DPRINT("- SET   Button: GPIO"); DPRINTLN(PIN_SET_BUTTON);
/*  
while (true) {
  DPRINT(digitalRead(PIN_MODE_SWITCH)); DPRINT(" / "); 
  DPRINT(digitalRead(PIN_FLD_BUTTON));  DPRINT(" / ");
  DPRINTLN(digitalRead(PIN_SET_BUTTON));
  delay(1000);
  }
*/  

  DPRINTLN("Starting RTC Clock...");    
  delay(1000);
  pinMode(PIN_SDA,OUTPUT); DPRINT("- SDA: GPIO"); DPRINTLN(PIN_SDA);
  pinMode(PIN_SCL,OUTPUT); DPRINT("- SCL: GPIO"); DPRINTLN(PIN_SCL);

  I2C_ClearBus();
  Wire.begin(PIN_SDA,PIN_SCL); 
  Wire.begin();   
  delay(100);
  Wire.beginTransmission(0x68);
  byte error = Wire.endTransmission();
  if (error == 0) {   //DS3231_get_addr(0x68)
    DPRINTLN("RTC found on 0x68.");
    DS3231_init(DS3231_CONTROL_INTCN);
    DS3231_get(&tim);
    checkWifiMode();
  }
  else { 
    DPRINTLN("!!!No RTC found on 0x68!!!");
    clockWifiMode = true;
  }
}


void editor() {
  DS3231_get(&tim);
  LastModify = 0;
  while (true) {
    scanButFLD(100); if (fld == 0) break;
    scanButSET(100);
    showValue();
    writeDisplaySingle();
    printDigits(1000);
    delay(100);
  }
  if (LastModify != 0) saveRTC();
}

void showValue() {
  memset(digit,10,sizeof(digit));   //clear array
  memset(digitDP,0,sizeof(digitDP));
  if(fld==1) {
    digit[3] = mvar[1] / 1000;
    digit[2] = (mvar[1]%1000) / 100;    
    digit[1] = (mvar[1]%100) / 10;
    digit[0] = mvar[1] % 10;
  }      
  else {
    digit[1] = mvar[fld] / 10;
    digit[0] = mvar[fld] % 10;
  }
}

//------------------------------------- RTC Clock functions --------------------------------------------------------------------
void updateRTC() {
  DS3231_get(&tim);
  if (abs(tim.sec - second())>1 || (tim.min != minute()) || (tim.hour != hour())  
      || (tim.mday != day()) || (tim.mon != month()) || (tim.year != year()) )   {
      DPRINTLN("Updating RTC from TimeServer...");
      DPRINT("- DS3231  date:"); DPRINT(tim.year); DPRINT("/"); DPRINT(tim.mon); DPRINT("/"); DPRINT(tim.mday); 
      DPRINT(" time:");  DPRINT(tim.hour); DPRINT(":"); DPRINT(tim.min); DPRINT(":"); DPRINTLN(tim.sec);    
      DPRINT("- Tserver date:"); DPRINT(year()); DPRINT("/"); DPRINT(month()); DPRINT("/"); DPRINT(day());      
      DPRINT(" time:");   DPRINT(hour()); DPRINT(":"); DPRINT(minute()); DPRINT(":"); DPRINTLN(second());  
      tim.sec = second();
      tim.min = minute();
      tim.hour = hour();
      tim.mday = day();
      tim.mon = month();
      tim.year = year(); 
      DS3231_set(tim); 
      }  //endif
}


void getRTC() {
  DS3231_get(&tim);
  setTime(tim.hour,tim.min,tim.sec,tim.mday,tim.mon,tim.year);  //set the time (hr,min,sec,day,mnth,yr)
  mvar[1] = tim.year; mvar[2] = tim.mon; mvar[3] = tim.mday;
  mvar[4] = tim.hour; mvar[5] = tim.min; 
}

void saveRTC() {
    DPRINTLN("Updating RTC from Manual settings...");
    tim.sec = 0;
    tim.min = mvar[5];
    tim.hour = mvar[4];
    tim.mday = mvar[3];
    tim.mon = mvar[2];
    tim.year = mvar[1]; 
    DPRINT("New RTC date:"); DPRINT(tim.year); DPRINT("/"); DPRINT(tim.mon); DPRINT("/"); DPRINT(tim.mday); 
    DPRINT(" time:");  DPRINT(tim.hour); DPRINT(":"); DPRINT(tim.min); DPRINT(":"); DPRINTLN(tim.sec);  
    DS3231_set(tim); 
}

//-------------------------- check buttons and switch  ------------------------------------------------
boolean checkWifiMode() {     //output TRUE, if mode changed
static unsigned long lastRun = millis(); 
static byte oldMode = 2;  

  if ((millis()-lastRun)<500) return false;
  lastRun = millis();
  //DPRINT(digitalRead(PIN_FLD_BUTTON)); DPRINT(" / "); DPRINTLN(digitalRead(PIN_SET_BUTTON));

  if (PIN_MODE_SWITCH==A0) {
    clockWifiMode = (analogRead(PIN_MODE_SWITCH)>100);
  }
  else {
    clockWifiMode = digitalRead(PIN_MODE_SWITCH);
  }
  
  if (oldMode != clockWifiMode) {
    if (oldMode!=2) {
      DPRINT("Clock switched to ");
      if (clockWifiMode) { 
        DPRINTLN("WIFI mode!");
        startWifiMode();
      }
      else 
        {
        DPRINTLN("MANUAL-RTC mode");          
        startStandaloneMode();
        }
    }  
    oldMode = (byte)clockWifiMode;
    return true;  
  }
  else
    return false;
}  

void scanButFLD(unsigned long mill) {
static unsigned long lastRun = millis(); 
static unsigned long lastPush = millis();; 
static boolean lastState = false;
static switchStates butState;
byte sw;

  if ((millis() - lastRun) < mill) return;   //refresh rate
  lastRun = millis(); 

  sw = digitalRead(PIN_FLD_BUTTON);
  switch (butState) {
    case IS_OPEN:   
      if(sw == LOW) butState = IS_PUSHING;  
      break; 
    case IS_PUSHING: 
      butState = IS_PUSHED;  
      lastState = true;  
      lastPush = millis();
      DPRINTLN(" PUSHED");
      break; 
    case IS_PUSHED:   
      if(sw == HIGH)  butState = IS_OPENING; 
      if((sw == LOW) && ((millis()-lastPush)>2000))  butState = IS_LONGPRESSING; 
      break; 
    case IS_LONGPRESSING:  
      butState = IS_LONGPRESSED; 
      DPRINTLN(" IS_LONGPRESSED");
      //if (noZero !=0) noZero =0; else noZero = 1;
      //EEPROM.update(EEPROM_NOZERO, noZero);  
      break; 
    case IS_LONGPRESSED:  
      if (sw == HIGH) butState = IS_LONGOPENING; 
      fld = 0;
      break;      
    case IS_OPENING:
      butState = IS_OPEN;
      lastState = false;      
      if ((millis()-lastPush)<500) {
           LastModify = millis();
          fld++;  if (fld>MAXFLD) fld = 0;
          DPRINT(m1[fld]._name); DPRINTLN(fld);
       } //endif millis()
      break; 
    case IS_LONGOPENING: 
      butState = IS_OPEN;
      lastState = false;  
      break;    
  } //end switch
}
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

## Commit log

2020-05-18 Add files via upload
    Individual brightness level setup possibility for each tube (digit)...
2020-05-18 Add files via upload
    Numitron Clock schematic and board
    [Numitron3.brd, Numitron3.sch]
2020-07-18 Add files via upload
    DHxx sensors added
2020-08-18 Add files via upload
    PCF8574 digit driver version working.

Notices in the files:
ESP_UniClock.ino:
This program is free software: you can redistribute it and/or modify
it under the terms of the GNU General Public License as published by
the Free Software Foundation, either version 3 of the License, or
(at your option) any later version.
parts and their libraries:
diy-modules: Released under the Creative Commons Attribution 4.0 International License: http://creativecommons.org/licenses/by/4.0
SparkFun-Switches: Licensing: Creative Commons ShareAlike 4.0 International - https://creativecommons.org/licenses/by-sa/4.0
